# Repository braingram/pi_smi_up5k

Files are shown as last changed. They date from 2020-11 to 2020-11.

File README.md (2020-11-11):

After reading a post on [iosoft.blog](https://iosoft.blog/) about the
[Raspberry Pi SMI interface](https://iosoft.blog/2020/07/16/raspberry-pi-smi/)
I wanted to test out using the interface for exchanging data with a FPGA.

This project involves some hardware and software (in verilog and python)
designed to test out the interface. There is no specific application for the
project (although I'm open to suggestions).

# Hardware

As described on the [iosoft blog post](https://iosoft.blog/2020/07/16/raspberry-pi-smi/)
SMI can use almost all the Pi GPIO pins. The only non-SMI pins are BCM pins 26 and 27.
A [FPGA hat](lattice_fpga_dev_board) was designed that connects to:

- all SMI pins
- BCM pin 27 as CRESET: to reset the FPGA
- BCM pin 26 as CDONE: to signify the FPGA programming is done
- 5V and GND for power

See [pinouts.csv](docs/pinouts.csv) for a full pinout table. Depending on what
Pi gpio pins your FPGA design uses you may have to disable several Pi interfaces
by modifying /boot/config.txt, removing kernel modules, and/or directly changing
gpio modes.

:exclamation: WARNING :exclamation: It is possible to have the Pi and FPGA fight
to drive pins which can cause regulators to get hot and magic blue smoke to escape.

The hat uses a lattice ice40-up5k in a 48-pin QFN package. The remaining FPGA pins
connect to:

- RGB led (using up5k led drivers)
- a 2x6 PMOD connector (:exclamation: WARNING :exclamation: the power and ground are swapped on the current design)

The hat does not include an oscillator and instead the up5k internal oscillator should be used.

## FPGA bitstream

For generating bitstreams the open source [icestorm](http://www.clifford.at/icestorm/) and [nextpnr](https://github.com/YosysHQ/nextpnr) tools were used.
The hat also does not include spi flash to hold the FPGA bitstream and the SPI_SS
pin of the FPGA is pulled low with a 10K resistor. To load a bitstream onto the
FPGA the Pi pins must be setup for SPI and the bistream sent to the FPGA using
a [custom python script](program.py) (similar to iceprog).

```bash
# enable SPI
sudo dtparam spi=on
# run in the same directory as program.py and provide a path to your bitstream file
python3 program.py bitstream.bit
```

# Software

The software for the project includes verilog and python code. The python
[program.py](program.py) script is used to reset and program the FPGA over
SPI. Other python scripts are included in some example project directories:

- [blink](blink): blink FPGA RGB leds
- [testpins](testpins): test (almost) all FPGA/Pi connections
- [spi](spi): FPGA as spi peripheral
- [spram](spram): read FPGA SPRAM over spi
- [smi](smi): read incrementing counter on FPGA over smi

Each example project includes verilog code, a Makefile for building the bitstream and
some contain python scripts for testing/interacting with the programmed FPGA.

# SMI Notes

## Using the SMI character device linux kernel modules

All of the testing used the [bcm2835_smi](https://github.com/raspberrypi/linux/blob/rpi-5.4.y/include/linux/broadcom/bcm2835_smi.h) and smi-dev kernel modules.
To load the modules several Pi peripherals must be disabled (i2c, spi, uart, etc).
When correctly loaded a character device should appear at /dev/smi
This character device can be read from to initiate reads on the SMI bus and
written to to initiate writes on the SMI bus. Settings can be changed by
issuing ioctl system calls.
Setting descriptions can be found in [bcm2835_smi.h](https://github.com/raspberrypi/linux/blob/rpi-5.4.y/include/linux/broadcom/bcm2835_smi.h#L68).
Defaults for these settings can be found in [bcm2835_smi.c](https://github.com/raspberrypi/linux/blob/rpi-5.4.y/drivers/misc/bcm2835_smi.c#L128).
The ioctl magic number is [0x1](https://github.com/raspberrypi/linux/blob/rpi-5.4.y/include/linux/broadcom/bcm2835_smi.h#L48)
and 3 types of requests are accepted:

- 0x0100: get settings
- 0x0101: set settings
- 0x0102: address

Get/set settings expect a Settings struct/Structure (as described in [bcm2835_smi.h](https://github.com/raspberrypi/linux/blob/rpi-5.4.y/include/linux/broadcom/bcm2835_smi.h#L68))
Address accepts an (up to 6 bit) address that will be asserted on the SMI bus
during read/write cycles.

## Pin electrical specs

### Address pins

SA5:SA0 are normally high (3.3 volts) and are asserted just prior to and
slightly after a read/write cycle (see the smi settings setup, hole, pace,
and strobe settings). SA5 is the most significant bit and a 0 address bit
results in a low (0 volt) signal. With the default settings the address
bus asserts ~8 ns prior to the read/write signal (see below) and deasserts
~8 ns after the read/write signal inactivates.

It seems like the smi driver is OK with not commanding all address pins
which could open up a few signals on the Pi.

### Control pins [SOE/SE, SWE/SRW]

SOE/SE is normally high and goes low during a read cycle

SWE/SRW is normally high and goes low during a write cycle

For both signals and default settings the low period is ~24 ns.

### Data pins

:exclamation: So far only pins SD0 to SD15 have been tested

These pins appear to be driven low when not in a read/write cycle which
means the FPGA must release (put into high-z) these pins when not
in a read cycle.

I'm not sure at what edge of SOE/SE the Pi reads the data pins but based
off NAND datasheets and iosoft notes I think it's the rising edge of SOE/SE.
This gives the FPGA ~24 ns from falling edge and ~32 ns from address
assertion to assert the data lines.

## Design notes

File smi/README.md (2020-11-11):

# Setup

Disable i2c, spi, camera [not sure if needed], uart
Enable smi & smi-dev in /boot/config.txt
```
dtparam=spi=off
dtparam=i2c_arm=off
dtparam=i2c0=off
dtparam=i2c1=off
enable_uart=0
dtoverlay=smi
dtoverlay=smi-dev
```

Not sure why some GPIO are still not in alt1 mode, force them after boot

```bash
# gpio 0,1,26,27 still in mode 'IN' [26 and 27 are fine]
sudo rmmod i2c-dev  # maybe blacklist this
gpio mode 30 alt1  # sets gpio 0
gpio mode 31 alt1  # sets gpio 1
```

Run gpio readall to see states of all pins
```bash
gpio readall
```

There should now be a /dev/smi device (with root permissions)

# Programming

To program the fpga you'll need to remove the smi modules and re-enable the SPI pins.

```bash
sudo rmmod bcm2835_smi_dev
sudo rmmod bcm2835_smi
sudo dtparam spi=on
```

After programming, disable SPI and re-enable smi

```bash
sudo dtparam spi=off
sudo modprobe bcm2835_smi
sudo modprobe bcm2835_smi_dev
```

# Notes

With default settings:
SA5:SA0: normally high (0=low) MSB-LSB, asserts ~8 ns before SOE/SWE falling edge, deasserts 8 ns after SOE/SWE rising
SOE/SE: normally high, goes low on read (data OK on falling edge?)
SWE/SRW: normally high, goes low on write (data OK on falling edge), low pulse duration is 24ns
SD15:SD0: ? 0=low 1=high MSB-LSB (when writing to /dev/smi order is LSByte then MSByte)

~16 ns between sequential writes, so bus is default 25 MHz giving throughput of 50 MBs (25 MBs if 8 bit)

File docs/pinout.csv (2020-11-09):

GPIO | ALT0 | ALT1 | PMOD | H/W pin | UP5K pin | Function | HW state | SMI state
0 | SDA0 | SA5 |  | 27 | 6 |  |  | Pull up
1 | SCL0 | SA4 |  | 28 | 9 |  |  | Pull up
2 | SDA1 | SA3 |  | 3 | 28 |  |  | Pull up
3 | SCL1 | SA2 |  | 5 | 27 |  |  | Pull up
4 | GPCLK0 | SA1 |  | 7 | 26 |  |  | Pull up
5 | GPCLK1 | SA0 |  | 29 | 4 |  |  | Pull up
6 | GPCLK2 | SOE/SE |  | 31 | 2 |  |  | Pull up
7 | SPI0_CE1 | SWE/SRW |  | 26 | 10 |  |  | Pull up
8 | SPI0_CE0 | SD0 |  | 24 | 11
9 | SPI0_MISO | SD1 |  | 21 | 14 | MISO
10 | SPI0_MOSI | SD2 |  | 19 | 17 | MOSI
11 | SPI0_SCLK | SD3 |  | 23 | 15 | SCLK
12 | PWM0 | SD4 |  | 32 | 3
13 | PWM1 | SD5 |  | 33 | 48
14 | TXD0 | SD6 |  | 8 | 25
15 | RXD0 | SD7 |  | 10 | 23
16 |  | SD8 |  | 36 | 47
17 |  | SD9 |  | 11 | 21
18 | PCM_CLK | SD10 |  | 12 | 20
19 | PCM_FS | SD11 |  | 35 | 46
20 | PCM_DIN | SD12 |  | 38 | 45
21 | PCM_DOUT | SD13 |  | 40 | 44
22 |  | SD14 |  | 15 | 19
23 |  | SD15 |  | 16 | 18
24 |  | SD16 |  | 18 | 13
25 |  | SD17 |  | 22 | 12
26 |  |  |  | 37 | 7 | CDONE | 2.2k pull up
27 |  |  |  | 13 | 8 | CRESET | 10K pull up
3V3 |  |  |  | 1, 17
5V |  |  |  | 2, 4
GND |  |  |  | 6, 9, 14, 20
GND |  |  |  | 25, 30, 34, 39
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

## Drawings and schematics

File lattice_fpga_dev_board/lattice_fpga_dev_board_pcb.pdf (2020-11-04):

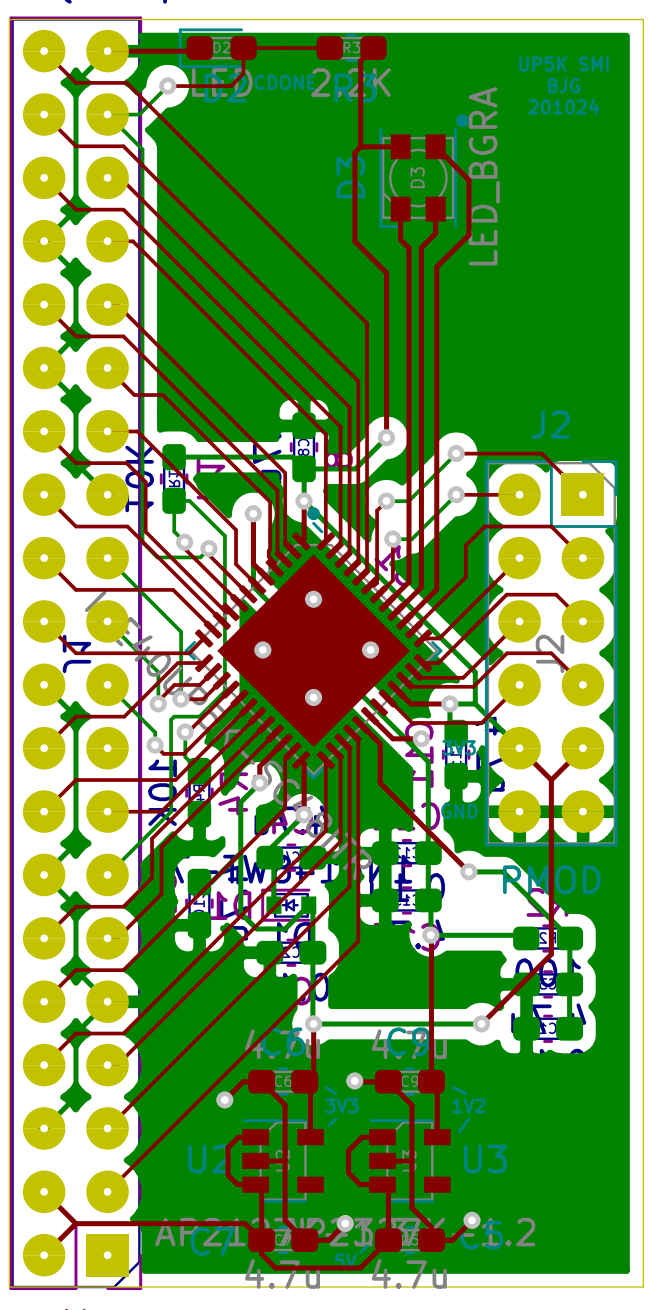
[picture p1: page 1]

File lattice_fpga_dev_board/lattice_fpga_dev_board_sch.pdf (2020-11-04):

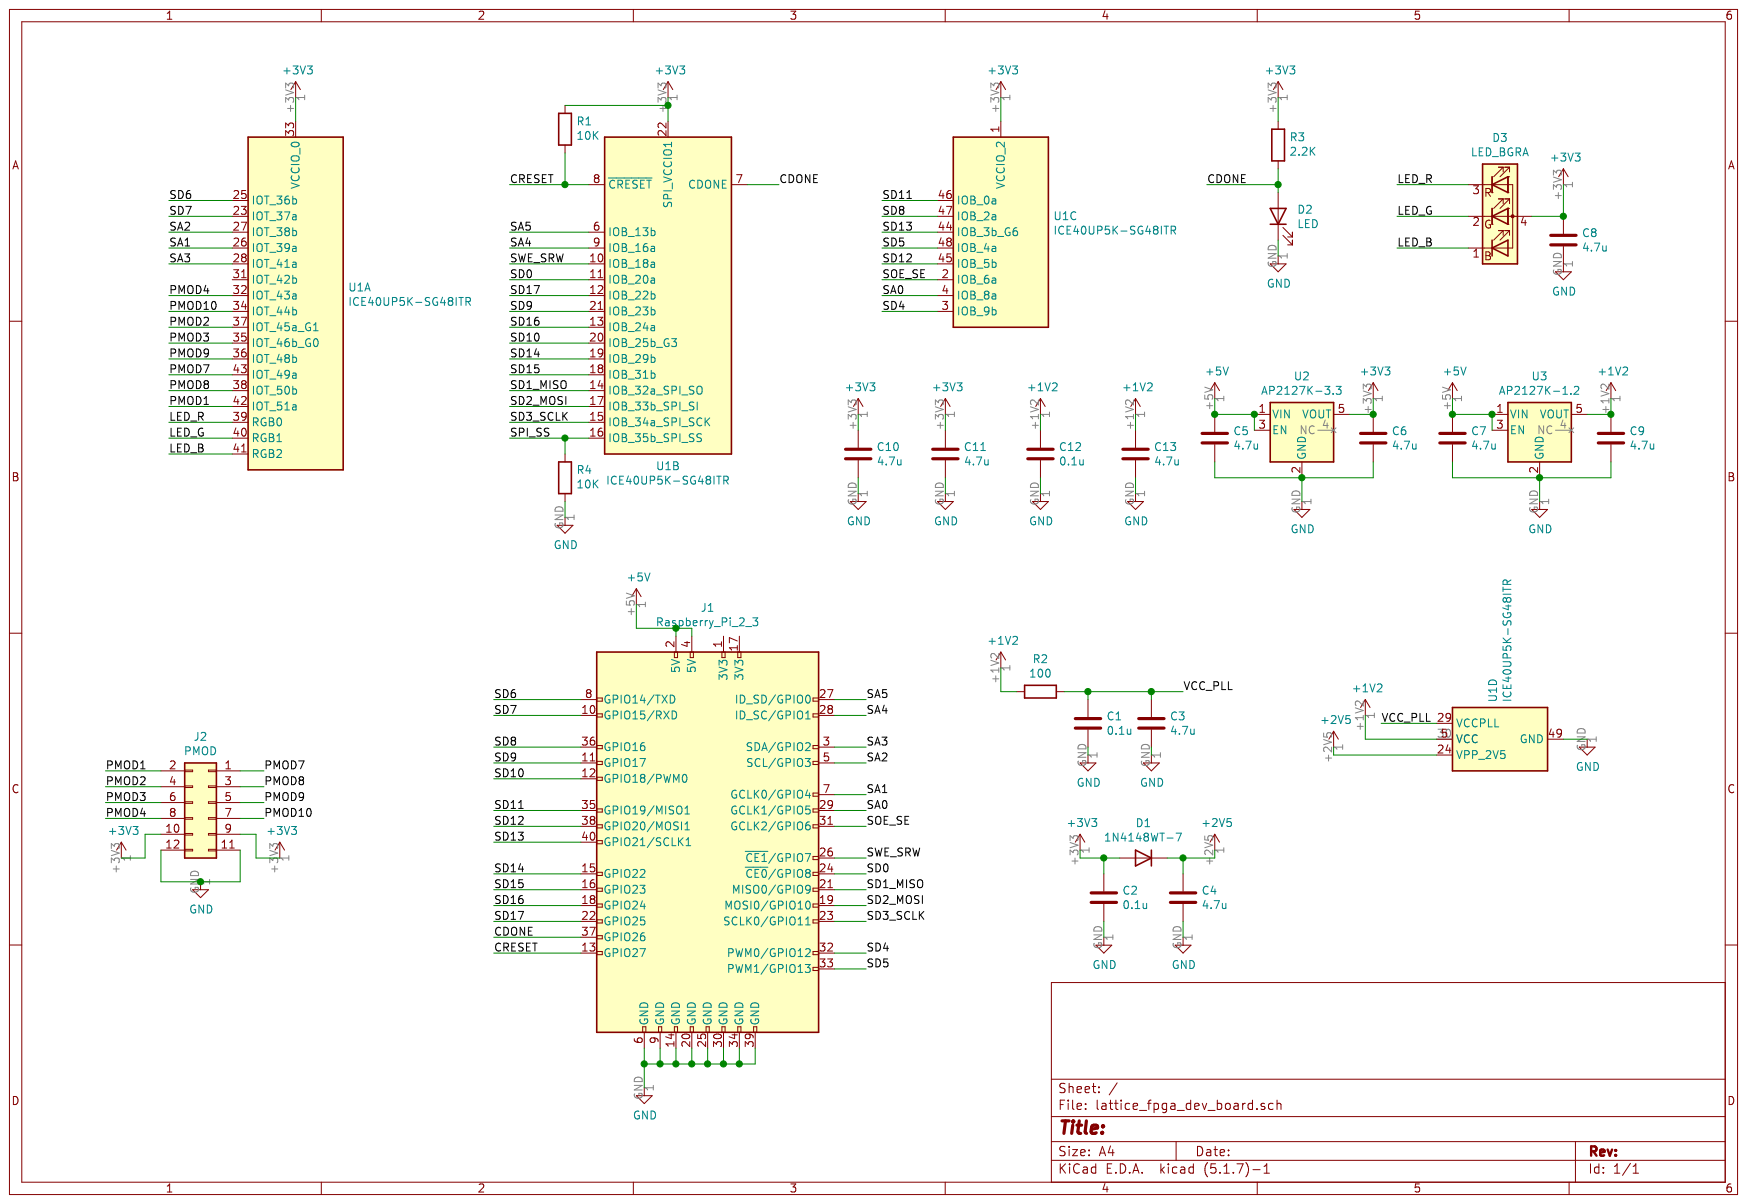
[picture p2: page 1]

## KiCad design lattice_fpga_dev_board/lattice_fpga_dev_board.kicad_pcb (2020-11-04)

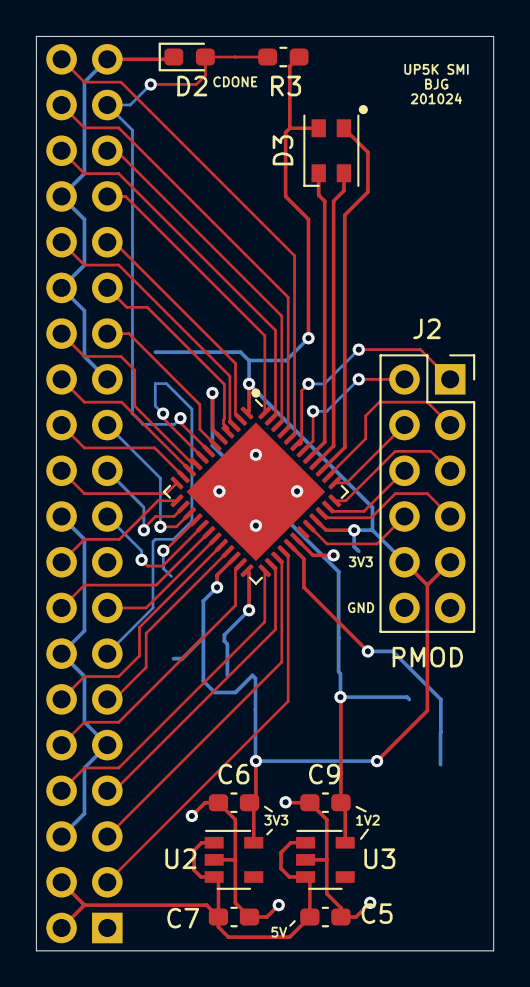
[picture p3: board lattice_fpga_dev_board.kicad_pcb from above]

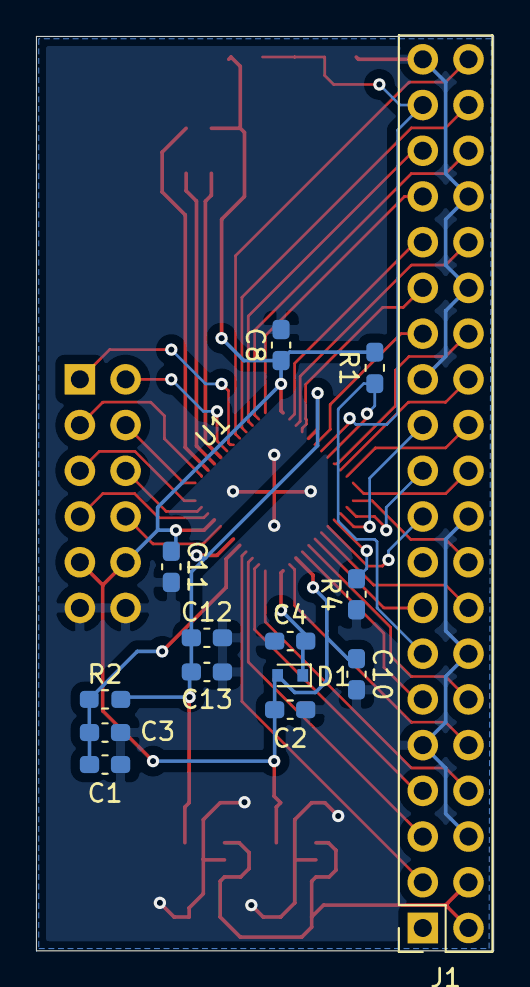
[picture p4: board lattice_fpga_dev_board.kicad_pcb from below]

Board: 2 copper layers, 25.4 x 50.8 mm, 25 parts (14 on the bottom side), 46 nets.

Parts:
C1, C2, C12: 0.1u; C_0603_1608Metric_Pad1.08x0.95mm_HandSolder
C3, C4, C5, C6, C7, C8, C9, C10, C11, C13: 4.7u; C_0603_1608Metric_Pad1.08x0.95mm_HandSolder
D1: 1N4148WT-7; D_SOD-523
D2: LED; LED_0603_1608Metric_Pad1.05x0.95mm_HandSolder
D3: LED_BGRA; LED_Cree-PLCC4_3.2x2.8mm_CCW
J1: Raspberry_Pi_2_3; PinSocket_2x20_P2.54mm_Vertical
J2: PMOD; PinSocket_2x06_P2.54mm_Vertical
R1: 10K; R_0603_1608Metric_Pad1.05x0.95mm_HandSolder
R2: 100; R_0603_1608Metric_Pad1.05x0.95mm_HandSolder
R3: 2.2K; R_0603_1608Metric_Pad1.05x0.95mm_HandSolder
R4: 10K; C_0603_1608Metric_Pad1.08x0.95mm_HandSolder
U1: ICE40UP5K-SG48ITR; QFN-48-1EP_7x7mm_P0.5mm_EP5.45x5.45mm
U2: AP2127K-3.3; SOT-23-5
U3: AP2127K-1.2; SOT-23-5

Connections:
+1V2: C9.1, C12.1, C13.1, R2.2, U1.5, U1.30, U3.5
+2V5: C4.1, D1.1, U1.24
+3V3: C2.1, C6.1, C8.1, C10.1, C11.1, D1.2, D3.4, J2.9, J2.10, R1.2, R3.2, U1.1, U1.22, U1.33, U2.5
+5V: C5.1, C7.1, J1.2, J1.4, U2.1, U2.3, U3.1, U3.3
/CDONE: D2.2, J1.37, R3.1, U1.7
/CRESET: J1.13, R1.1, U1.8
/LED_B: D3.1, U1.41
/LED_G: D3.2, U1.40
/LED_R: D3.3, U1.39
/PMOD1: J2.2, U1.42
/PMOD2: J2.4, U1.37
/PMOD3: J2.6, U1.35
/PMOD4: J2.8, U1.32
/PMOD7: J2.1, U1.43
/PMOD8: J2.3, U1.38
/PMOD9: J2.5, U1.36
/PMOD10: J2.7, U1.34
/SA0: J1.29, U1.4
/SA1: J1.7, U1.26
/SA2: J1.5, U1.27
/SA3: J1.3, U1.28
/SA4: J1.28, U1.9
/SA5: J1.27, U1.6
/SD0: J1.24, U1.11
/SD1_MISO: J1.21, U1.14
/SD2_MOSI: J1.19, U1.17
/SD3_SCLK: J1.23, U1.15
/SD4: J1.32, U1.3
/SD5: J1.33, U1.48
/SD6: J1.8, U1.25
/SD7: J1.10, U1.23
/SD8: J1.36, U1.47
/SD9: J1.11, U1.21
/SD10: J1.12, U1.20
/SD11: J1.35, U1.46
/SD12: J1.38, U1.45
/SD13: J1.40, U1.44
/SD14: J1.15, U1.19
/SD15: J1.16, U1.18
/SD16: J1.18, U1.13
/SD17: J1.22, U1.12
/SOE_SE: J1.31, U1.2
/SPI_SS: R4.2, U1.16
/SWE_SRW: J1.26, U1.10
/VCC_PLL: C1.1, C3.1, R2.1, U1.29
GND: C1.2, C2.2, C3.2, C4.2, C5.2, C6.2, C7.2, C8.2, C9.2, C10.2, C11.2, C12.2, C13.2, D2.1, J1.6, J1.9, J1.14, J1.20, J1.25, J1.30, J1.34, J1.39, J2.11, J2.12, R4.1, U1.49, U2.2, U3.2

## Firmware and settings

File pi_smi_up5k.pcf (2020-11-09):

# spi pins (overlaps with gpio/smi) [pi names]
set_io SPI_CE0 10
set_io SPI_CE1 11
set_io SPI_MISO 14
set_io SPI_MOSI 17
set_io SPI_SCLK 15

# i2c pins (overlaps with gpio/smi) no HW pullups [pi names]
set_io I2C_SDA0 6
set_io I2C_SCL0 9
set_io I2C_SDA1 28
set_io I2C_SCL1 27

# uart pins (overlaps with gpio/smi) [pi names]
set_io UART_TX 25
set_io UART_RX 23

# pcm pins (overlaps with gpio/smi) [pi names]
set_io PCM_CLK 20
set_io PCM_FS 46
set_io PCM_DIN 45
set_io PCM_DOUT 44

# pwm pins (overlaps with gpio/smi) [pi names]
set_io PWM0 3
set_io PWM1 48

# gpclk pins (overlaps with gpio/smi) [pi names]
set_io GPCLK0 26
set_io GPCLK1 4
set_io GPCLK2 2

# blinky blinky
set_io RGB0 39  # blue
set_io RGB1 40  # green
set_io RGB2 41  # red

# GPI pins (takes ALL pi pins)
set_io GPIO0 6
set_io GPIO1 9
set_io GPIO2 28
set_io GPIO3 27
set_io GPIO4 26
set_io GPIO5 4
set_io GPIO6 2
set_io GPIO7 10
set_io GPIO8 11
set_io GPIO9 14
set_io GPIO10 17
set_io GPIO11 15
set_io GPIO12 3
set_io GPIO13 48
set_io GPIO14 25
set_io GPIO15 23
set_io GPIO16 47
set_io GPIO17 21
set_io GPIO18 20
set_io GPIO19 46
set_io GPIO20 45
set_io GPIO21 44
set_io GPIO22 19
set_io GPIO23 18
set_io GPIO24 13
set_io GPIO25 12

# SMI pins (takes ALL pi pins)
set_io SMI_SA5 6
set_io SMI_SA4 9
set_io SMI_SA3 28
set_io SMI_SA2 27
set_io SMI_SA1 26
set_io SMI_SA0 4
set_io SMI_SOE 2
set_io SMI_SWE 10
set_io SMI_SD0 11
set_io SMI_SD1 14
set_io SMI_SD2 17
set_io SMI_SD3 15
set_io SMI_SD4 3
set_io SMI_SD5 48
set_io SMI_SD6 25
set_io SMI_SD7 23
set_io SMI_SD8 47
set_io SMI_SD9 21
set_io SMI_SD10 20
set_io SMI_SD11 46
set_io SMI_SD12 45
set_io SMI_SD13 44
set_io SMI_SD14 19
set_io SMI_SD15 18
set_io SMI_SD16 13
set_io SMI_SD17 12

# pmod pins (no overlap with smi/pi)
set_io PMOD1 42
set_io PMOD2 37
set_io PMOD3 35
set_io PMOD4 32
set_io PMOD7 43
set_io PMOD8 38
set_io PMOD9 36
set_io PMOD10 34

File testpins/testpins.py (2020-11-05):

import time

import RPi.GPIO as GPIO


in_pins = [0, 1, 2, 3, 4, 5, 6, 7, 8]
in_pins += [12, 13, 14, 15, 16, 17, 18, 19, 20, 21, 22, 23, 24]
clk_pin = 25

GPIO.setmode(GPIO.BCM)
print(f"seting up pin {clk_pin} as clock")
GPIO.setup(clk_pin, GPIO.OUT, initial=GPIO.LOW)
for p in in_pins:
    print(f"seting up pin {p} as input")
    GPIO.setup(p, GPIO.IN, pull_up_down=GPIO.PUD_OFF)


def toggle_clock():
    GPIO.output(clk_pin, 1)
    GPIO.output(clk_pin, 0)


def pin_states():
    states = {}
    for p in in_pins:
        states[p] = GPIO.input(p)
    return states


def format_pin_states(s):
    return ''.join(['*' if s[p] else '_' for p in in_pins])


def test_all_pins():
    high_fails = {}
    low_fails = {}
    # all GPIO should start low
    if any(pin_states().values()):
        print("all pins did not start low")
        low_fails['pre'] = True
    #assert not any(pin_states().values()), "all pins did not start low"
    for p in in_pins:
        print(f"toggling clock for pin {p}")
        toggle_clock()
        s = pin_states()
        print(format_pin_states(s))
        if s[p] == 0:
            print(f"expected {p} to be high and was low")
            high_fails[p] = True
        #assert s[p], f"expected {p} to be high and was low"
        for o in in_pins:
            if o == p:
                continue
            if s[o] == 1:
                print(f"expect {o} to be low and was high")
                low_fails[p] = low_fails.get(p, []) + [o, ]
            #assert s[o] == 0, f"expect {o} to be low and was high"

    # and should end low
    toggle_clock()
    if any(pin_states().values()):
        print("all pins did not end low")
        low_fails['post'] = True
    #assert not any(pin_states().values()), "all pins did not end low"
    return high_fails, low_fails

#toggle_clock()
#print(format_pin_states(pin_states()))
print(test_all_pins())

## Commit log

2020-11-04 adding kicad files
    [lattice_fpga_dev_board.kicad_pcb, lattice_fpga_dev_board.sch]
2020-11-09 adding pinout csv file
    [pinout.csv]
2020-11-09 starting spi verilog code
2020-11-09 adding reset script and python test spi script
2020-11-09 fixing simple spi test verilog
2020-11-10 minor updates to spi test
